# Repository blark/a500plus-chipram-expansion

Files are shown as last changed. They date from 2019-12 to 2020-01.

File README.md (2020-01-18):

# a500plus-chipram-expansion

This is a 1MB chip RAM expansion designed for the Amiga 500+ in KiCad.

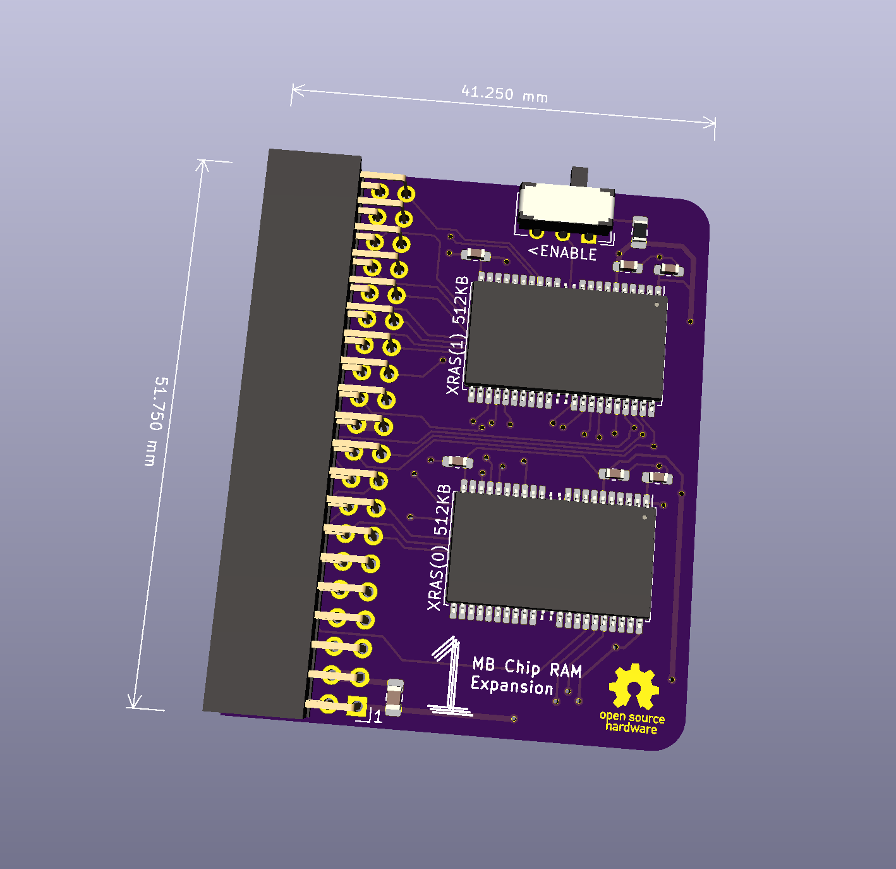
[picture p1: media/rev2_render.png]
a500plus-chipram board image


It is in the experimental phase, but I've assembled it and it appears to be working great. However, you've been warned!

## Features

Small (42mmx52mm), simple design using only a 40 pin (2x20) female 2.54mm connector. The remaining pins are for the RTC which is on-board the A500+, so they are unecessary for RAM expansion. This makes it possible to use a 40 pin connector, which is cheaper and easier to find.

WARNING: **make sure you plug it in correctly** see the [install section](https://github.com/blark/a500plus-chipram-expansion#install) below.

## Schematic

A PDF file of the schematic can be found [in this repo](https://raw.githubusercontent.com/blark/a500plus-chipram-expansion/master/media/schematic.pdf).

## Ordering

I shared the design at [Oshpark](https://oshpark.com/shared_projects/eQQuG4Mi)

## BOM
| Designator | Description |
| --- | --- |
| J1 | 40P (20x2) female header 2.54mm |
| J2 | 1x DPDT Sub-Miniature Slide switch (9x4x3.5mm, easily found on Ebay) |
| U1-U2 | IS41C16257-35T 4mbit DRAM (256 x 16) |
| C1-C6 | 100nF 603 SMD capacitor |
| C7 | 10uF 805 SMD capacitor |
| R1 | 10K 805 SMD resistor |

## Install

Be careful during install to match pin 1 on the expansion with pin 1 on the A500+ memory expansion port! Here's an image of how it should be installed:

a500plus-chipram board install orientation

## Thanks

The parts library I've included (and expanded upon) in this repo is "borrowed" from [Kai Robinson](https://github.com/kr239) check out his great projects!

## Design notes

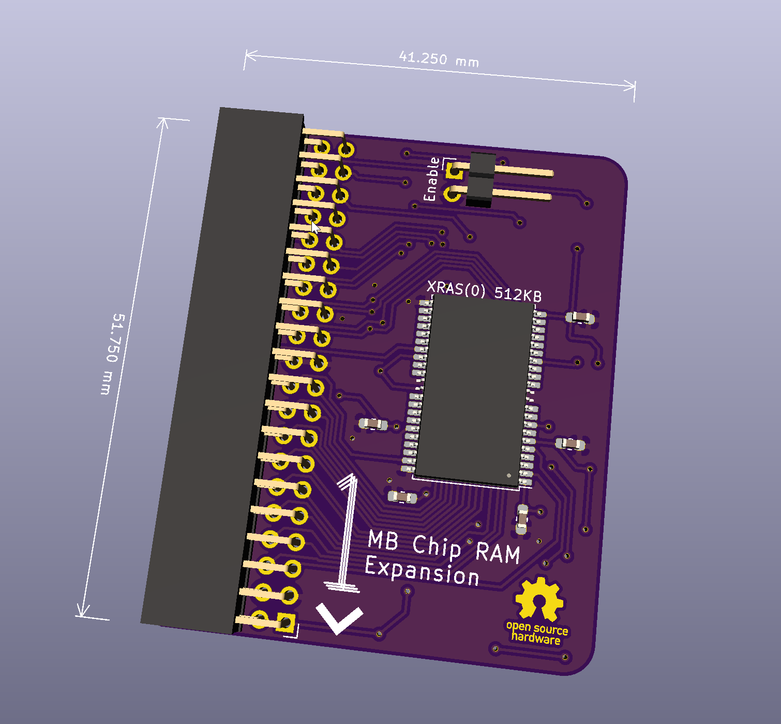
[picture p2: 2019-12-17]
media/rev1_render.png

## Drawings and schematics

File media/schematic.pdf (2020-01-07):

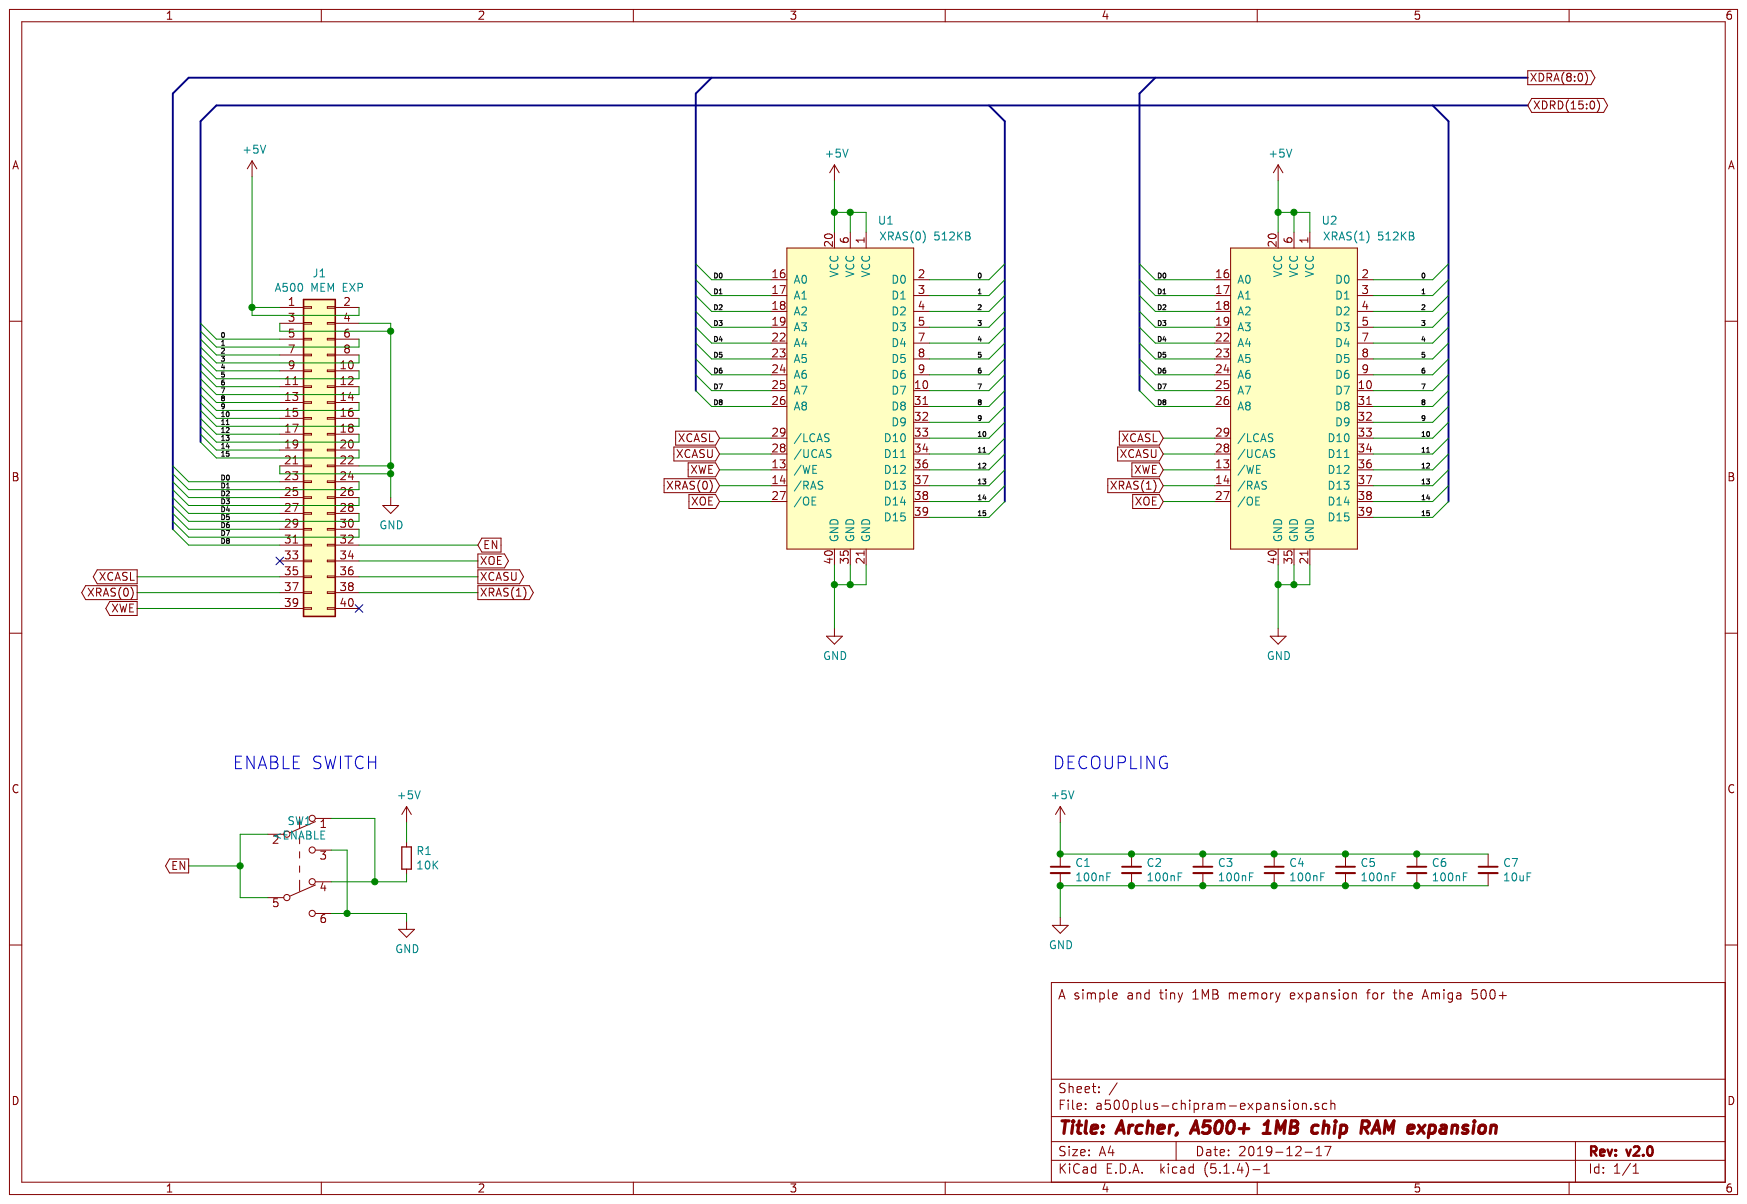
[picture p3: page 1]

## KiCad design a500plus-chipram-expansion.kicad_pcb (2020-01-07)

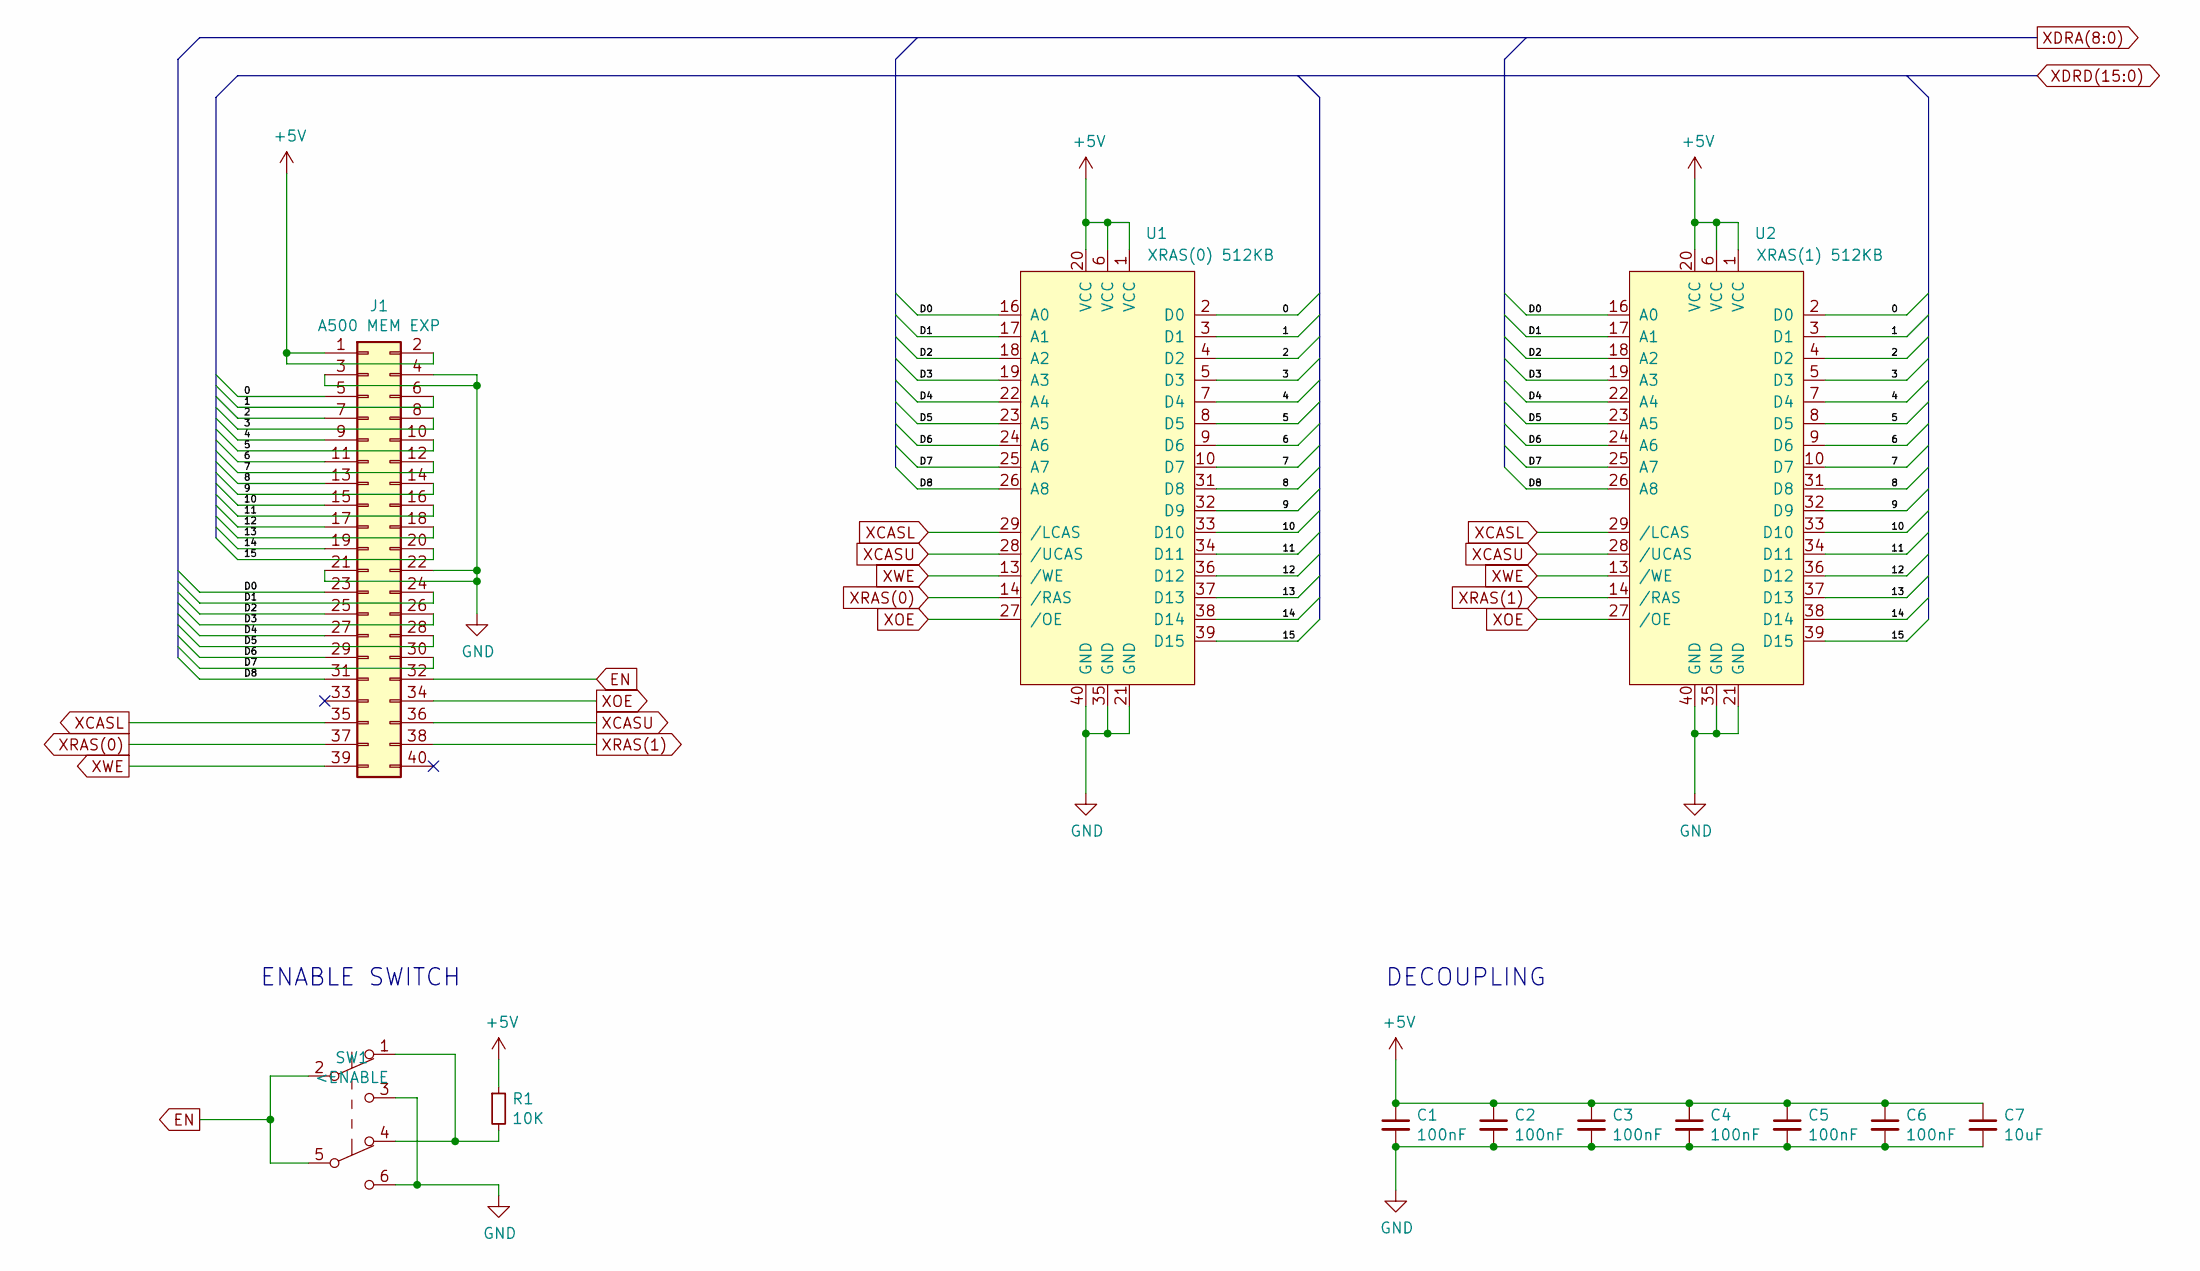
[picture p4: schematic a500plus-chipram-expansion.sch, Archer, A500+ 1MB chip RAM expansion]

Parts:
C1, C2, C3, C4, C5, C6: 100nF; C_0603_1608Metric_Pad1.05x0.95mm_HandSolder
C7: 10uF; C_0805_2012Metric_Pad1.15x1.40mm_HandSolder
J1: A500 MEM EXP; PinHeader_2x20_P2.54mm_Horizontal
R1: 10K; R_0805_2012Metric_Pad1.15x1.40mm_HandSolder
SW1: <ENABLE; SW_CuK_JS202011AQN_DPDT_Angled
U1: XRAS(0) 512KB; TSOP-II-40
U2: XRAS(1) 512KB; TSOP-II-40

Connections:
+5V: C1.1, C2.1, C3.1, C4.1, C5.1, C6.1, C7.1, J1.1, J1.2, R1.1, U1.1 (VCC), U1.6 (VCC), U1.20 (VCC), U2.1 (VCC), U2.6 (VCC), U2.20 (VCC)
/0: J1.5, U1.2 (D0), U2.2 (D0)
/1: J1.6, U1.3 (D1), U2.3 (D1)
/2: J1.7, U1.4 (D2), U2.4 (D2)
/3: J1.8, U1.5 (D3), U2.5 (D3)
/4: J1.9, U1.7 (D4), U2.7 (D4)
/5: J1.10, U1.8 (D5), U2.8 (D5)
/6: J1.11, U1.9 (D6), U2.9 (D6)
/7: J1.12, U1.10 (D7), U2.10 (D7)
/8: J1.13, U1.31 (D8), U2.31 (D8)
/9: J1.14, U1.32 (D9), U2.32 (D9)
/10: J1.15, U1.33 (D10), U2.33 (D10)
/11: J1.16, U1.34 (D11), U2.34 (D11)
/12: J1.17, U1.36 (D12), U2.36 (D12)
/13: J1.18, U1.37 (D13), U2.37 (D13)
/14: J1.19, U1.38 (D14), U2.38 (D14)
/15: J1.20, U1.39 (D15), U2.39 (D15)
/D0: J1.23, U1.16 (A0), U2.16 (A0)
/D1: J1.24, U1.17 (A1), U2.17 (A1)
/D2: J1.25, U1.18 (A2), U2.18 (A2)
/D3: J1.26, U1.19 (A3), U2.19 (A3)
/D4: J1.27, U1.22 (A4), U2.22 (A4)
/D5: J1.28, U1.23 (A5), U2.23 (A5)
/D6: J1.29, U1.24 (A6), U2.24 (A6)
/D7: J1.30, U1.25 (A7), U2.25 (A7)
/D8: J1.31, U1.26 (A8), U2.26 (A8)
EN: J1.32, SW1.2 (B), SW1.5 (B)
GND: C1.2, C2.2, C3.2, C4.2, C5.2, C6.2, C7.2, J1.3, J1.4, J1.21, J1.22, SW1.3 (C), SW1.6 (C), U1.21 (GND), U1.35 (GND), U1.40 (GND), U2.21 (GND), U2.35 (GND), U2.40 (GND)
unnamed: R1.2, SW1.1 (A), SW1.4 (A)
XCASL: J1.35, U1.29 (/LCAS), U2.29 (/LCAS)
XCASU: J1.36, U1.28 (/UCAS), U2.28 (/UCAS)
XOE: J1.34, U1.27 (/OE), U2.27 (/OE)
XRAS(0): J1.37, U1.14 (/RAS)
XRAS(1): J1.38, U2.14 (/RAS)
XWE: J1.39, U1.13 (/WE), U2.13 (/WE)

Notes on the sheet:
DECOUPLING
ENABLE SWITCH

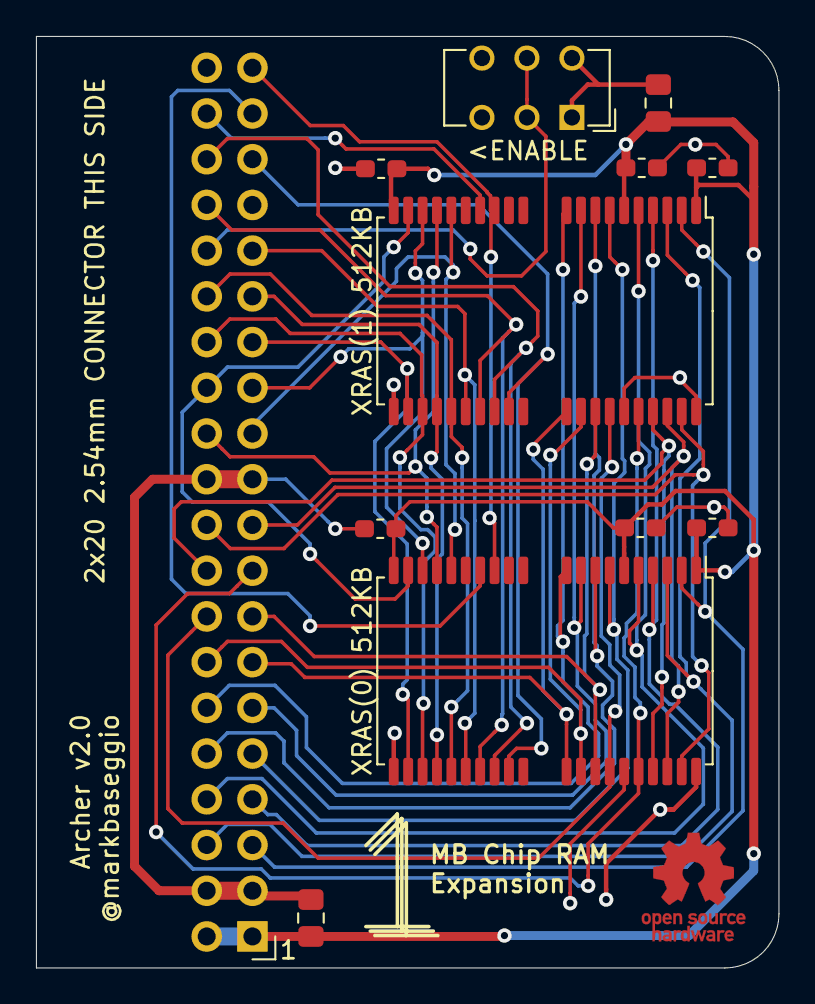
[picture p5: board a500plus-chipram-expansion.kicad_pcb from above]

Board: 2 copper layers, 41.2 x 51.8 mm, 12 parts (0 on the bottom side), 35 nets.

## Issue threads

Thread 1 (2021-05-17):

Different chip

Avinitlarge, 2021-05-17:
I love this design but the chips used are a bit obscure. Big ask, could it be redesigned to use a more commonly available chip?

PRETTY PLEASE :D

blark, 2021-05-17:
You can get the chips from utsource.

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

Avinitlarge, 2021-05-17:
Shipping to the UK is nearly twice as much at the chips ☹️

Avinitlarge, 2021-06-18:
Order 5 boards and 20 chips from UTsource, built 2 up and neither working in my 500+. Tried with 2 chip, 1 chip but nothing at all 😭

Avinitlarge, 2021-06-23:
I’ve found 4 other chips that work with this now.

blark, 2021-06-24:
Glad to hear that you got it working.

Closed 2021-06-24.

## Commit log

2020-01-07 v2 gerbers first commit
    [a500plus-chipram-expansion-B_Cu.gbr, a500plus-chipram-expansion-B_Mask.gbr, a500plus-chipram-expansion-B_Paste.gbr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]
2020-01-07 BOM change
